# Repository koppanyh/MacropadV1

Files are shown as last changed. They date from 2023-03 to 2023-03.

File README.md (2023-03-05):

# MacropadV1
My first totally custom macropad build!

PCB manufacturing files and schematic can be found in the PCB directory.

Run the demo sketch in the Demo directory to verify the macropad as assembled correctly.
It's programmed with the older Arduino IDE version 1.8, with the pro micro as an Arduino Leonardo.

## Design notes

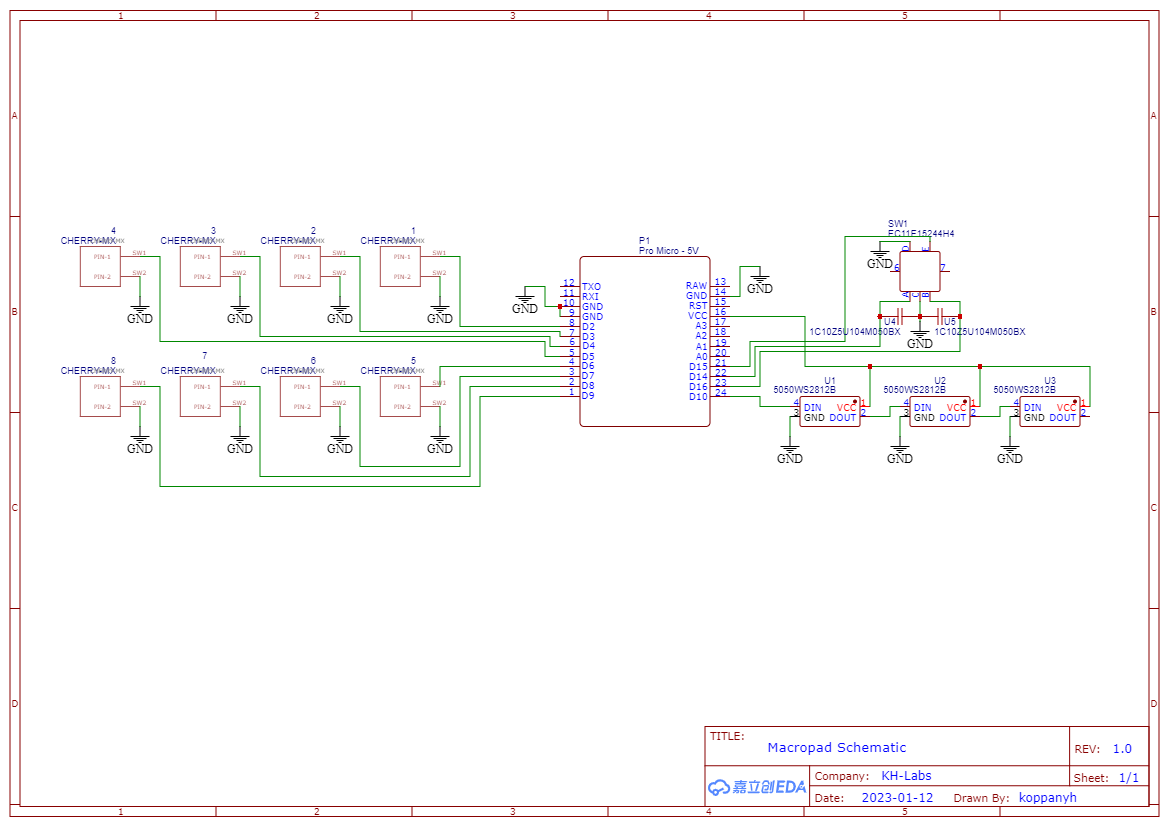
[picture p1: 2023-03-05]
PCB/Schematic_Macropad V1_2023-01-16.png

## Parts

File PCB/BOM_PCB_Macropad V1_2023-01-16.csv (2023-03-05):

ID | Name | Designator | Footprint | Quantity | Manufacturer Part | Manufacturer | Supplier | Supplier Part | Price
1 | CHERRY-MX | 1,2,3,4,5,6,7,8 | CHERRY-MX | 8
2 | EC11E15244H4 | SW1 | SW-TH_EC11E15244H4 | 1 | EC11E15244H4 | ALPSALPINE | LCSC | C1322539 | 0.339
3 | 5050WS2812B | U2,U1,U3 | LED-SMD_5050WS2812B | 3 | 5050WS2812B | null | LCSC | C2874876
4 | 1C10Z5U104M050BX | U4,U5 | CAP-TH_L5.1-W3.2-P2.54-D0.5 | 2 | 1C10Z5U104M050BX | VISHAY(威世) | LCSC | C1620206 | 0.016
5 | Pro Micro - 5V | P1 | PRO MICRO - 5V | 1

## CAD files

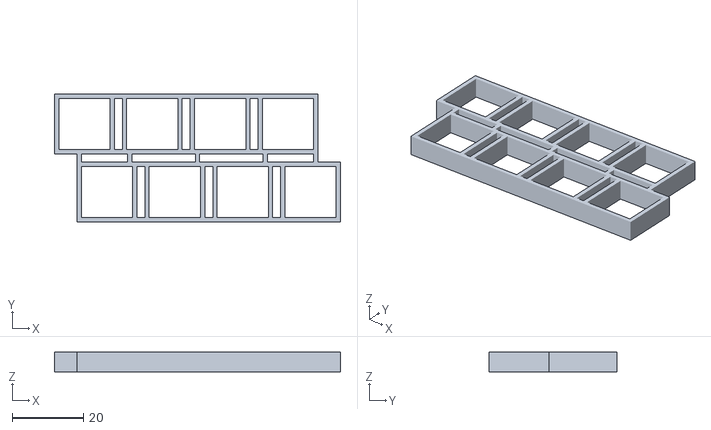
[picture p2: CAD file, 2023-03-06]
3DPrinted/Macropad_V1_Plate.stl
80.3 x 35.8 x 5.60

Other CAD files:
3DPrinted/Macropad_V1_Plate.f3d

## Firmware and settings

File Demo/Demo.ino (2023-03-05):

// Modified by @koppanyh from the following:
// NeoPixel Ring simple sketch (c) 2013 Shae Erisson
// Released under the GPLv3 license to match the rest of the Adafruit NeoPixel library

#include <Adafruit_NeoPixel.h>

const int onboard_led_pin = 17;

const int neopixel_pin = 10;
const int neopixel_len = 3;

// When setting up the NeoPixel library, we tell it how many pixels,
// and which pin to use to send signals. Note that for older NeoPixel
// strips you might need to change the third parameter -- see the
// strandtest example for more information on possible values.
Adafruit_NeoPixel pixels(neopixel_len, neopixel_pin, NEO_GRB + NEO_KHZ800);

int key_pins[] = {2, 3, 4, 5, 6, 7, 8, 9};
const int keys_len = sizeof(key_pins) / sizeof(int);
const int button_pin = 15;
const int encoder_clk = 14;
const int encoder_data = 16;

const uint32_t black = pixels.Color(0, 0, 0);
int brightness = 1;
uint32_t colors[] = {
  pixels.Color(1, 0, 0),
  pixels.Color(0, 1, 0),
  pixels.Color(0, 0, 1)
};
const int colors_len = sizeof(colors) / sizeof(uint32_t);
int selected_color = 1;
void InitColors() {
  colors[0] = pixels.Color(brightness, 0, 0);
  colors[1] = pixels.Color(0, brightness, 0);
  colors[2] = pixels.Color(0, 0, brightness);
}

int currentStateCLK;
int lastStateCLK;

void setup() {
  pixels.begin(); // INITIALIZE NeoPixel strip object (REQUIRED)
  
  pinMode(onboard_led_pin, OUTPUT);  // init onboard LED
  digitalWrite(onboard_led_pin, LOW);  // onboard LED won't light without this for some reason, and it's inverted...
  delay(500);
  digitalWrite(onboard_led_pin, LOW);

  BootAnim();

  for (int i = 0; i < keys_len; i++)
    pinMode(key_pins[i], INPUT_PULLUP);
  pinMode(button_pin, INPUT_PULLUP);
  pinMode(encoder_clk, INPUT_PULLUP);
  pinMode(encoder_data, INPUT_PULLUP);

  // Read the initial state of CLK
  lastStateCLK = digitalRead(encoder_clk);
}

void BootAnim() {
  digitalWrite(onboard_led_pin, LOW);
  pixels.clear();
  pixels.setPixelColor(0, pixels.Color(1, 0, 0));
  pixels.show();
  delay(500);
  pixels.setPixelColor(1, pixels.Color(0, 1, 0));
  pixels.show();
  delay(500);
  pixels.setPixelColor(2, pixels.Color(0, 0, 1));
  pixels.show();
  delay(500);
  digitalWrite(onboard_led_pin, HIGH);
}

void BinaryDisp(uint8_t num) {
  pixels.clear(); // Set all pixel colors to 'off'
  // The first NeoPixel in a strand is #0, second is 1, all the way up
  // to the count of pixels minus one.
  for(int i = 0; i < neopixel_len; i++) { // For each pixel...
    // pixels.Color() takes RGB values, from 0,0,0 up to 255,255,255
    // Here we're using a moderately bright green color:
    if (num & 1)
      pixels.setPixelColor(i, colors[selected_color]);
    else
      pixels.setPixelColor(i, black);
    num >>= 1;
  }
  pixels.show();   // Send the updated pixel colors to the hardware.
}

void loop() {
  // Show which key is pressed
  BinaryDisp(0);
  for (int i = 0; i < keys_len; i++) {
    if (!digitalRead(key_pins[i]))
      BinaryDisp(i == 0 ? 7 : i);
  }
  
  // Use the encoder button to rotate through colors
  if(!digitalRead(button_pin)) {
    selected_color++;
    if (selected_color >= colors_len)
      selected_color = 0;
    delay(100);
  }
  
  // Encoder
  for (int i = 0; i < 100; i++) {
    // Read the current state of CLK
    currentStateCLK = !digitalRead(encoder_clk);
    // If last and current state of CLK are different, then pulse occurred
    // React to only 1 state change to avoid double count
    if (currentStateCLK != lastStateCLK  && currentStateCLK){
      // If the DT state is different than the CLK state then
      // the encoder is rotating CCW so decrement
      if (!digitalRead(encoder_data) != currentStateCLK) {
        brightness --;
      } else {
        // Encoder is rotating CW so increment
        brightness ++;
      }
      brightness = max(min(255, brightness), 0);
      InitColors();
    }
    // Remember last CLK state
    lastStateCLK = currentStateCLK;
    delay(1);
  }
  
  //delay(100);
}

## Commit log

2023-03-05 Added PCB files and demo sketch
    [BOM_PCB_Macropad V1_2023-01-16.csv, PickAndPlace_PCB_Macropad V1_2023-01-16.csv]
2023-03-06 Designed printable plate for stabilizing switches
    [Macropad_V1_Plate.f3d, Macropad_V1_Plate.stl]
